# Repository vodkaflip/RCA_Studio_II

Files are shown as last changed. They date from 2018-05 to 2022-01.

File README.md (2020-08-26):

# RCA Studio II

## Multicart Hardware
The cartridge uses a 512k flash chip (SST39SF040) to provide 128 selectable 4k slots to the RCA Studio II Console. The cartridge has a latch circuit for the higher address lines. The original version of the multicart had a dual retriggerable monostable multi-vibrator (courtesy of Ed Keefe) to ‘repair’ the TPA line, which is crippled on most console cartridge ports. A jumper selects whether the cartridge generates this signal (bridge the top two pins of the jumper, default) or whether it uses the one generated by the console (bottom two pins). The latter is needed for some older versions of the Studio II and for the color clones.

The newer version (v5) of the multicart no longer needs the patch circuit: it mixes in the /MRD signal to generate working CE and OE for the EEPROM to work correctly. 

A switch selects whether $000-$3FF is addressable on the cartridge. This will bypass the console's roms/kernels so that Chip-8 games or alternative kernels can be used.

The Multicart PCB has provisions to replace the two hex encoders that select the ROM slot with a microview arduino. In combination with a single rotary dial, a slot can be selected an activated.

## Updating Multicart
If new ROMs become available, the flash memory on the cartridge can be updated to include these. Note that the entire image (512k) will probably need to be rewritten to the chip. This requires a programmer that supports the 39SF040 flash memory chip, which should be most devices. Since the chip is a PLCC32 package, an adapter is probably needed. Check the AtariAge forums for news and help if needed.

### SLOT STRUCTURE (4096 bytes)
```
$xy000-$xy3FF	KERNEL
$xy400-$xy7FF	Low ROM area
$xy800-$xyBFF	[not used by cart - console RAM]
$xyC00-$xyFFF	High ROM area

where	x = high bank select (MSB)
	    y = low bank select (LSB)
```

See the readme in the eeprom directory for more details on how the eeprom image can be 'compiled'.

## Single cart Hardware
This is very similar to the multicart design, apart from the slot selection rotary encoders. And it uses a much smaller eprom: 2716 or 2732 - this needs to be set via a jumper. A switch (or jumper) can determine whether the console uses $000-$3ff from the cartridge or from the console. It allows different kernels to be run from the cart (e.g. Chip-8 games).

## CARTRIDGE SLOT
Since the cartridge slot is unprotected on this 40 year old console, corrosion of the contacts is very likely. This will hamper correct operation of the cartridge and is a likely source of problems/crashes you may experience. If that’s the case, please ensure that the cartridge slot pins on the back row are clean. Use contact cleaner or similar if necessary.

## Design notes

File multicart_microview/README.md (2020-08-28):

# Alternative for Hex Selection

Revisions 4.5 and 5.0 of the RCA Studio II Multicart can accomodate a Sparkfun Microview module with built-in OLED screen for selecting the ROM slots. Selection is done using a single rotary encoder: dial to select a slot and push to activate. The console then needs to be reset to start the game.

## Hardware

The two hex encoders and the resistor network can be removed. The following components need to be added:

* Mechanical Encoder: Bourns PEC12R-4120F-S0012 (https://www.mouser.be/ProductDetail/652-PEC12R-4120F-S12)
* Sparkfun Microview: https://www.mouser.be/Search/Refine?Keyword=microview
* C1-C4: 0.1uF
* optional: a 6-pin header to connect an FTDI interface that allows the Microview module to be reprogrammed (if it is not socketed)

## Software
### Splash Screen

### Main

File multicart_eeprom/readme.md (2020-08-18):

The python 3 script *create_rom.py* compiles an image for the eeprom on the multicart. When using a 512k eeprom like the 39sf040, there’s 8 banks of 16 slots available.

```
Bank0
   ——— 0-game0_1.bin
   ——— 1-game0_2.bin
   ——— …
   ——— e-game0_14.bin
   ——— f-empty.bin
Bank1
   ——— 0-game1_1.bin
   ———…
…
Bank7
   ——— 0-game1_1.bin
   ——— 1-game0_2.bin
   ——— …
   ——— e-game0_14.bin
   ——— f-empty.bin
```

The script will add the appropriate kernel before the game rom. Each 4k slot will have the following structure:
```
$000 - $3ff = kernel
$400 - $7ff = game rom
$800 - $bff = dummy value - this area is not mapped to the cartridge
$c00 - $fff = game rom (only for larger games)
```

The script will decide which kernel to use based on the extension of the game rom:
```
.bin --> standard RCA Studio II kernel
.vic --> Victory/MPA-02/PAL clone kernel
.ch8 --> chip8 kernel by Marcel
```

Note that not all chip8 game will work and even if they do, the keyboard layout may not make much sense.

The script will insert the ROM filename at $a00 - this enables the Emma 02 emulator to display the name of the ROM when using the multicart binary image.

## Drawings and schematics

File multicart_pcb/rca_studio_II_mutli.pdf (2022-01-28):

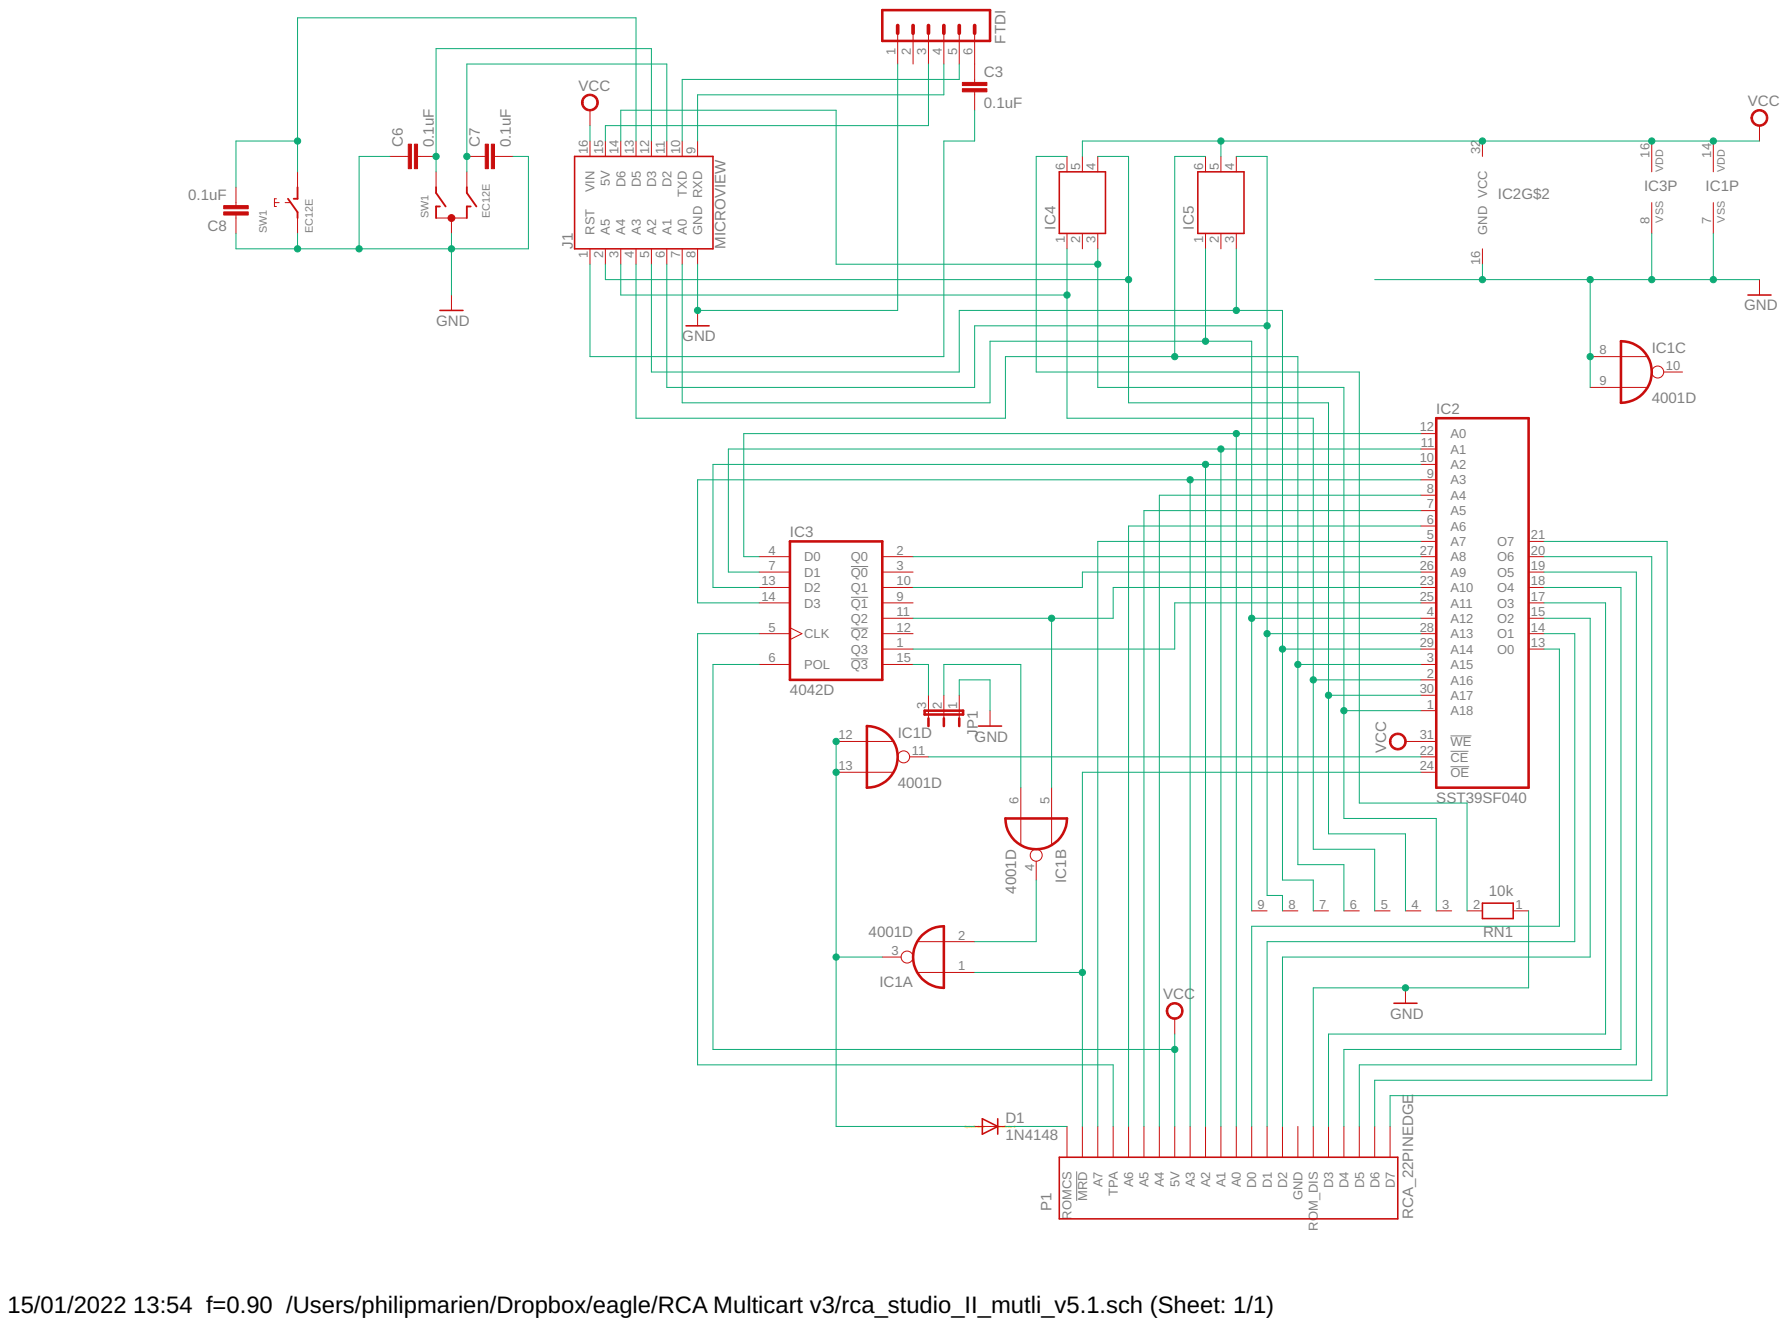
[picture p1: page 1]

VCC

15/01/2022 13:54 f=0.90 /Users/philipmarien/Dropbox/eagle/RCA Multicart v3/rca_studio_II_mutli_v5.1.sch (Sheet: 1/1)

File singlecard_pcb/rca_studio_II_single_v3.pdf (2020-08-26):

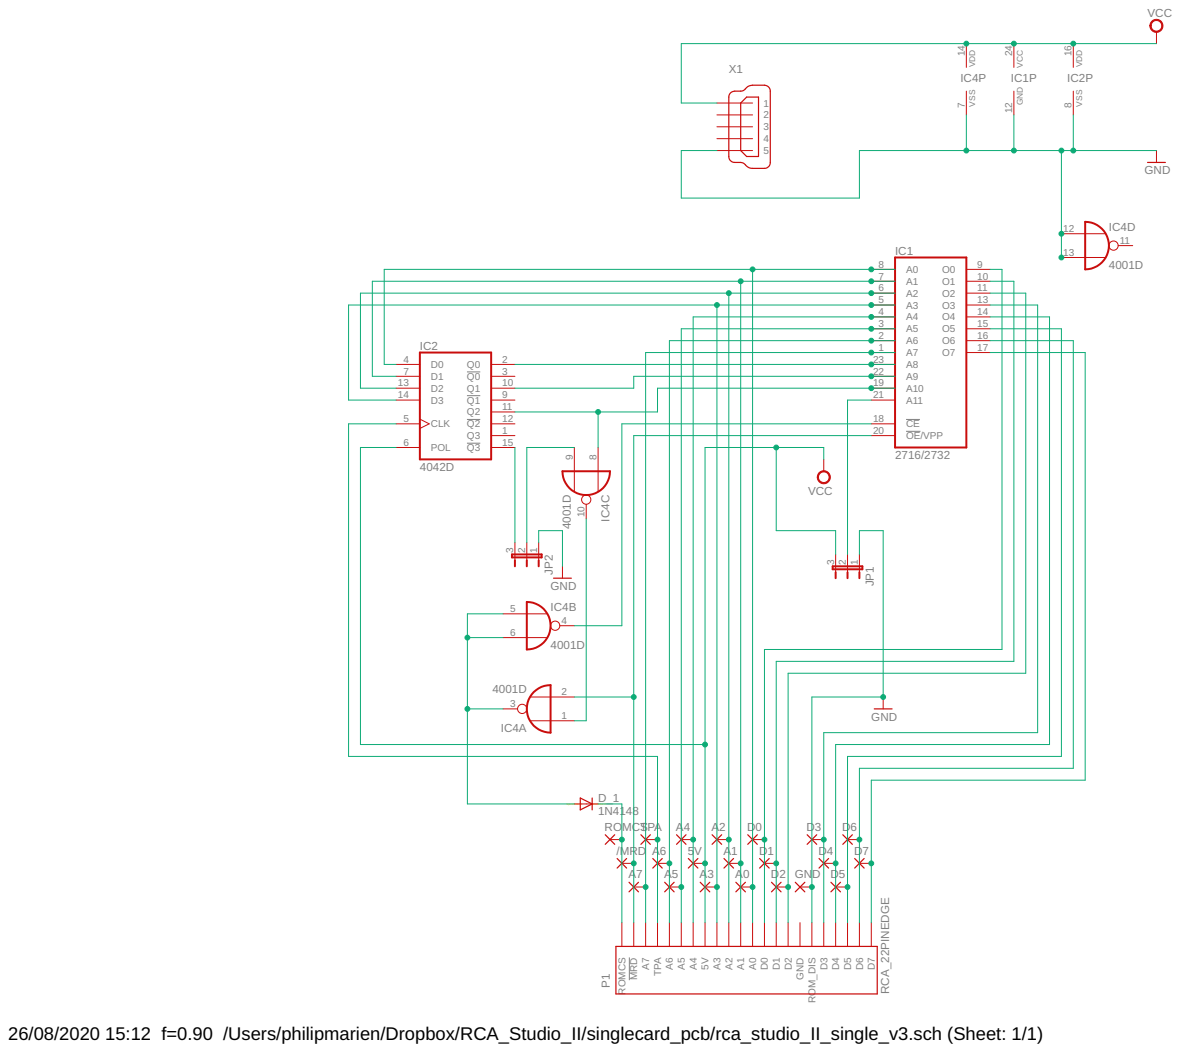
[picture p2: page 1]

26/08/2020 15:12 f=0.90 /Users/philipmarien/Dropbox/RCA_Studio_II/singlecard_pcb/rca_studio_II_single_v3.sch (Sheet: 1/1)

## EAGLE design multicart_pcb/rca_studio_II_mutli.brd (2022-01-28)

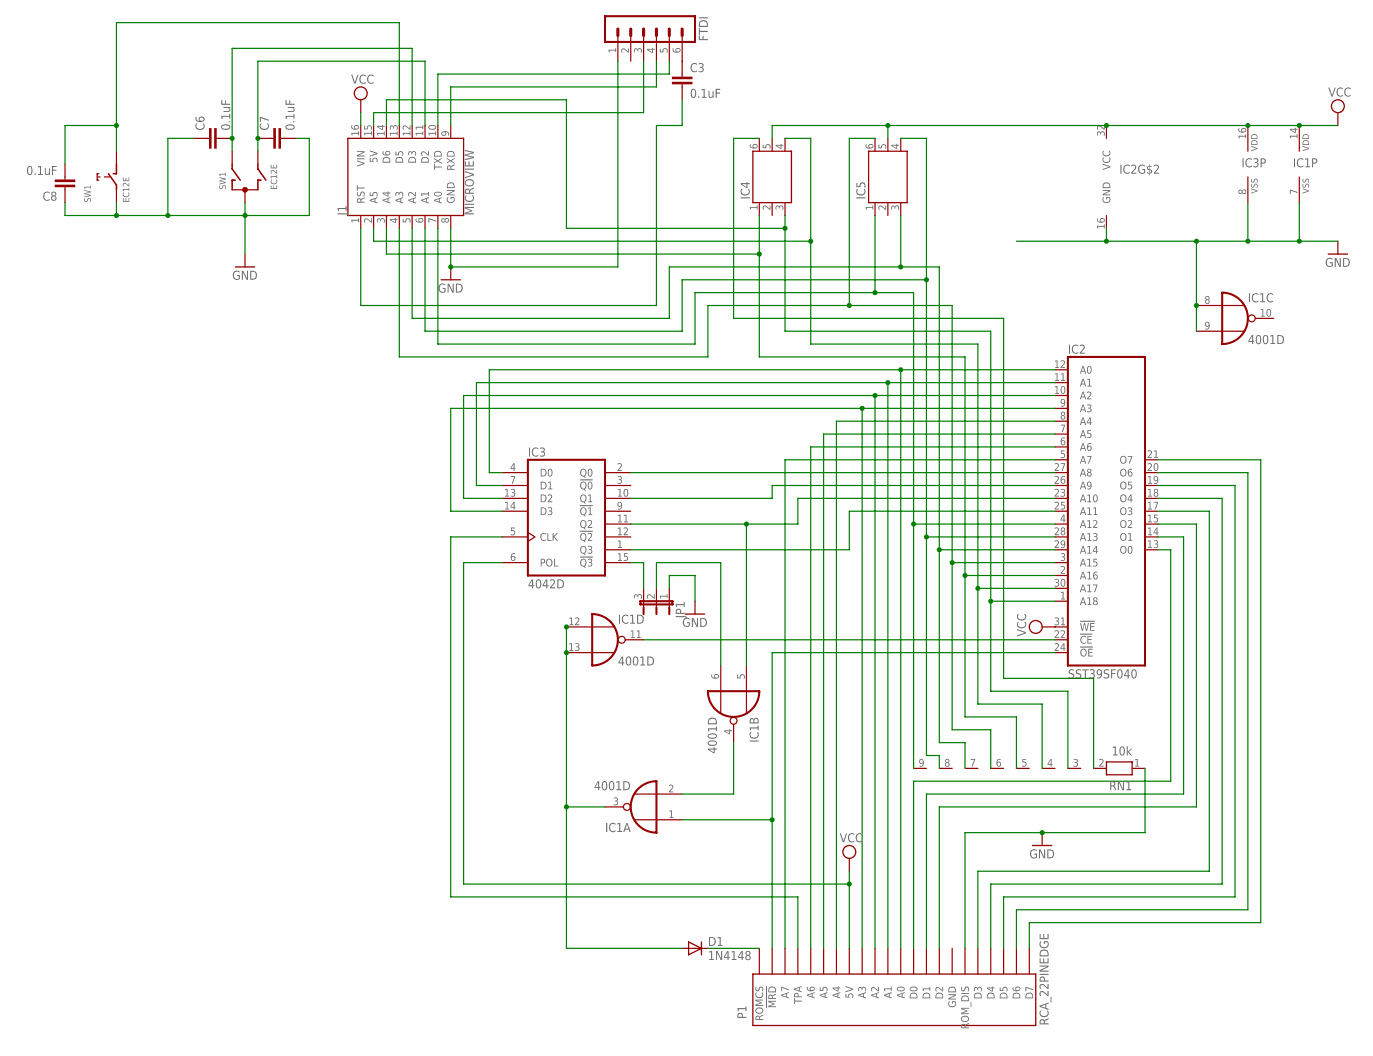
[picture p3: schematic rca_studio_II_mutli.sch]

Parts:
C3, C6, C7, C8: 0.1uF; C0805
D1: 1N4148; DO35-7
FTDI: MA06-1
IC1: 4001D; SO14
IC2: SST39SF040; S32
IC3: 4042D; SO16
IC4, IC5: HEXENCODERHEXENCODER; HEXENCODER
J1: MICROVIEW; MV-DIP16-NODIMENSION
JP1: JP2E; JP2
P1: RCA_22PINEDGE
RN1: 10k; RN-9
SW1: EC12E; ALPS_EC12E_SW

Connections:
A0: IC2.12 (A0), IC3.4 (D0), P1.11 (A0)
A1: IC2.11 (A1), IC3.7 (D1), P1.12 (A1)
A2: IC2.10 (A2), IC3.13 (D2), P1.13 (A2)
A3: IC2.9 (A3), IC3.14 (D3), P1.14 (A3)
A4: IC2.8 (A4), P1.16 (A4)
A5: IC2.7 (A5), P1.17 (A5)
A6: IC2.6 (A6), P1.18 (A6)
A7: IC2.5 (A7), P1.20 (A7)
A8: IC2.27 (A8), IC3.2 (Q0)
A9: IC2.26 (A9), IC3.10 (Q1)
A10: IC1.5 (I0), IC2.23 (A10), IC3.11 (Q2)
A11: IC2.25 (A11), IC3.1 (Q3)
A12: IC2.4 (A12), IC5.1, J1.7 (A0), RN1.9
A13: IC2.28 (A13), IC5.4 (2), J1.6 (A1), RN1.8
A14: IC2.29 (A14), IC5.3 (4), J1.5 (A2), RN1.7
A15: IC2.3 (A15), IC5.6 (8), J1.4 (A3), RN1.6
A16: IC2.2 (A16), IC4.1, J1.3 (A4), RN1.5
A17: IC2.30 (A17), IC4.4 (2), J1.2 (A5), RN1.4
A18: IC2.1 (A18), IC4.3 (4), J1.14 (D6), RN1.3
GND: C6.1, C7.2, C8.1, FTDI.1, IC1.7 (VSS), IC1.8 (I0), IC1.9 (I1), IC2.16 (GND), IC3.8 (VSS), J1.8 (GND), JP1.1, P1.6 (ROM_DIS), RN1.1, SW1.C, SW1.E (2)
unnamed: IC1.11 (O), IC2.22 (!CE)
unnamed: IC2.21 (O7), P1.1 (D7)
unnamed: IC2.20 (O6), P1.2 (D6)
unnamed: IC2.19 (O5), P1.3 (D5)
unnamed: IC2.18 (O4), P1.4 (D4)
unnamed: IC2.17 (O3), P1.5 (D3)
unnamed: IC2.15 (O2), P1.8 (D2)
unnamed: IC2.14 (O1), P1.9 (D1)
unnamed: IC2.13 (O0), P1.10 (D0)
unnamed: C6.2, J1.12 (D3), SW1.A
unnamed: IC1.1 (I0), IC2.24 (!OE), P1.21 (!MRD)
unnamed: C7.1, J1.11 (D2), SW1.B
unnamed: IC1.2 (I1), IC1.4 (O)
unnamed: D1.A, IC1.3 (O), IC1.12 (I0), IC1.13 (I1)
unnamed: C8.2, J1.13 (D5), SW1.D (1)
unnamed: IC3.15 (!Q3), JP1.3
unnamed: FTDI.3, J1.15 (5V)
unnamed: FTDI.4, J1.9 (RXD)
unnamed: FTDI.5, J1.10 (TXD)
unnamed: C3.2, J1.1 (RST)
unnamed: C3.1, FTDI.6
unnamed: IC1.6 (I1), JP1.2
unnamed: D1.C, P1.22 (ROMCS)
unnamed: IC4.6 (8), RN1.2
unnamed: IC3.5 (CLK), P1.19 (TPA)
VCC: IC1.14 (VDD), IC2.31 (!WE), IC2.32 (VCC), IC3.6 (POL), IC3.16 (VDD), IC4.5 (C2), IC5.5 (C2), J1.16 (VIN), P1.15 (5V)

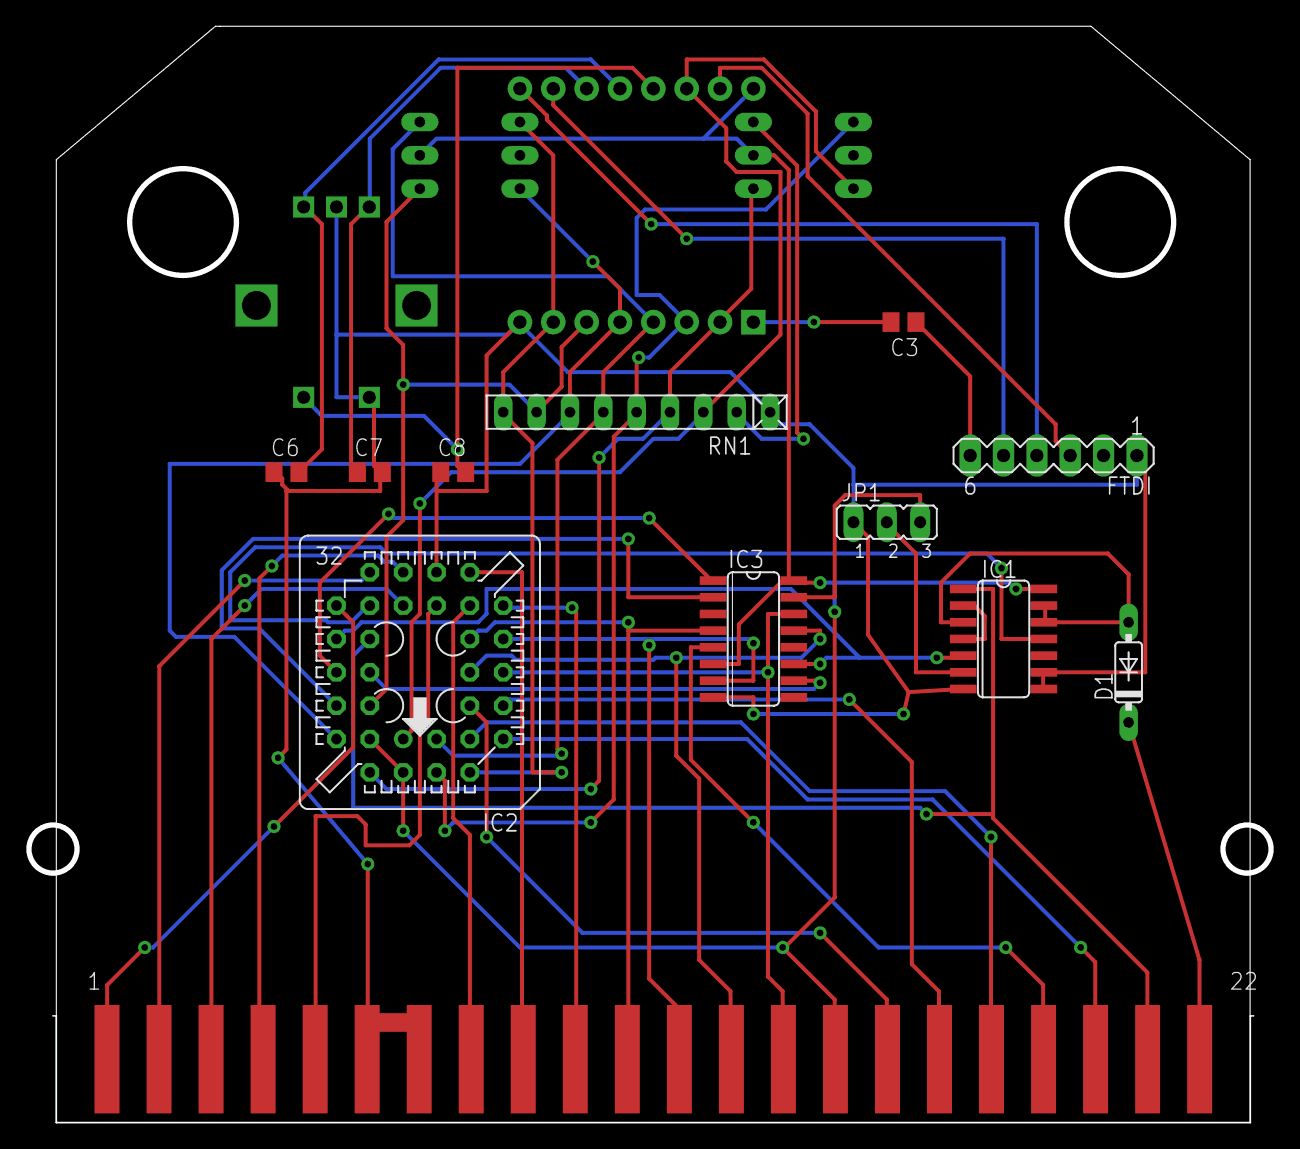
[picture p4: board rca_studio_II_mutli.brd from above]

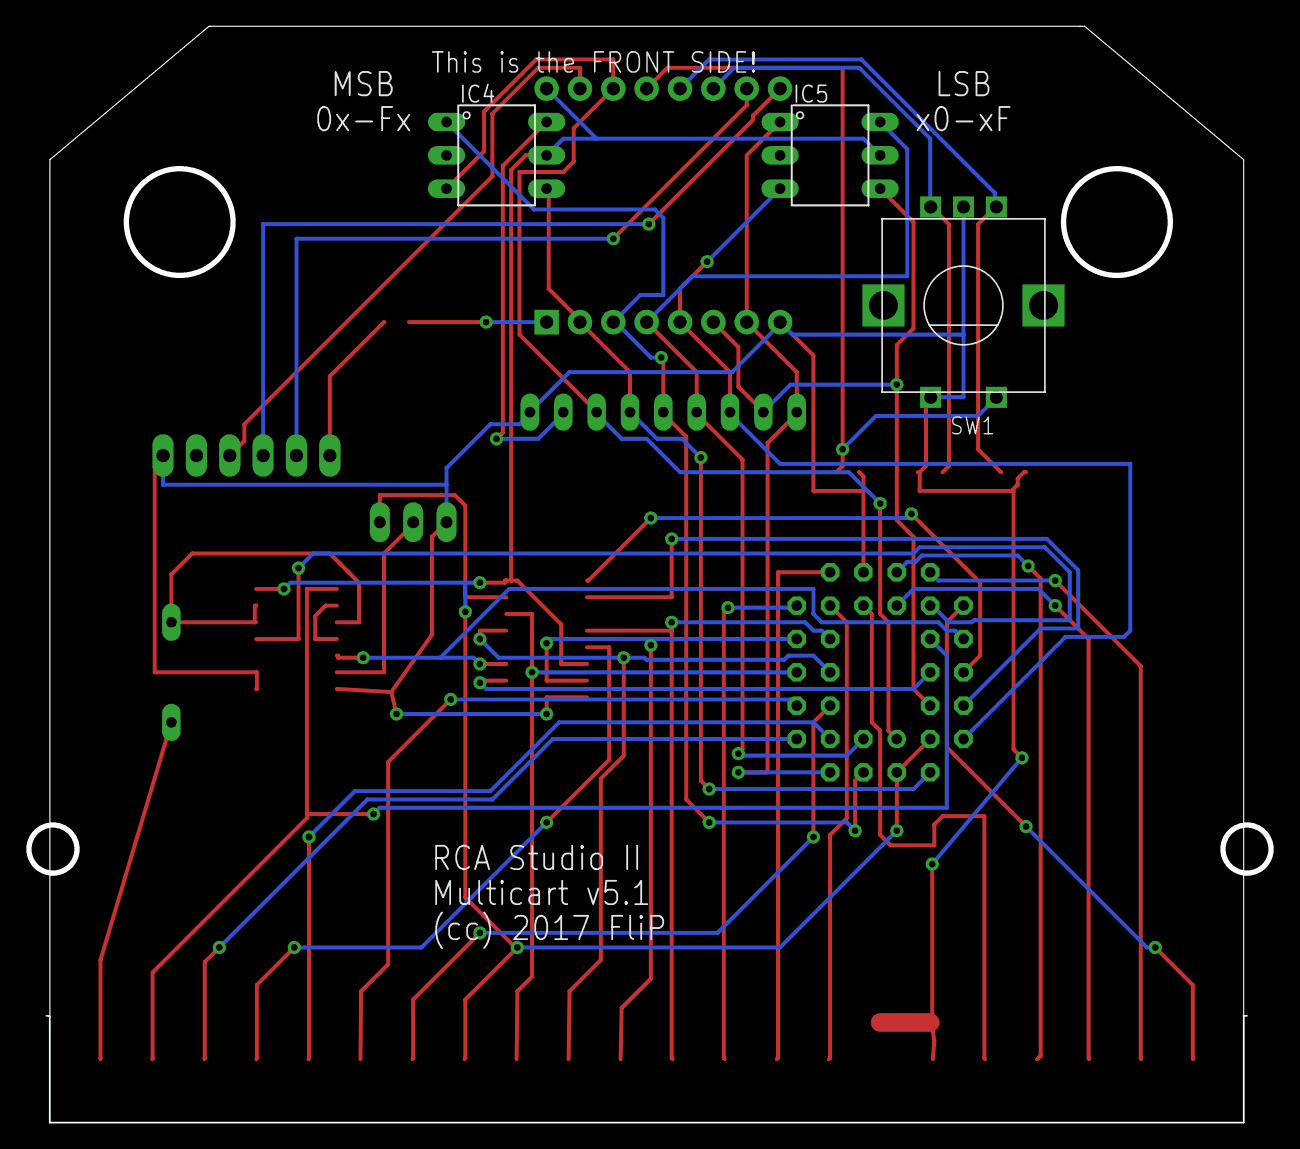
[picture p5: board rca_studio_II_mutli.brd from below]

Board: 2 copper layers, 94.6 x 83.5 mm, 16 parts (4 on the bottom side), 46 nets.

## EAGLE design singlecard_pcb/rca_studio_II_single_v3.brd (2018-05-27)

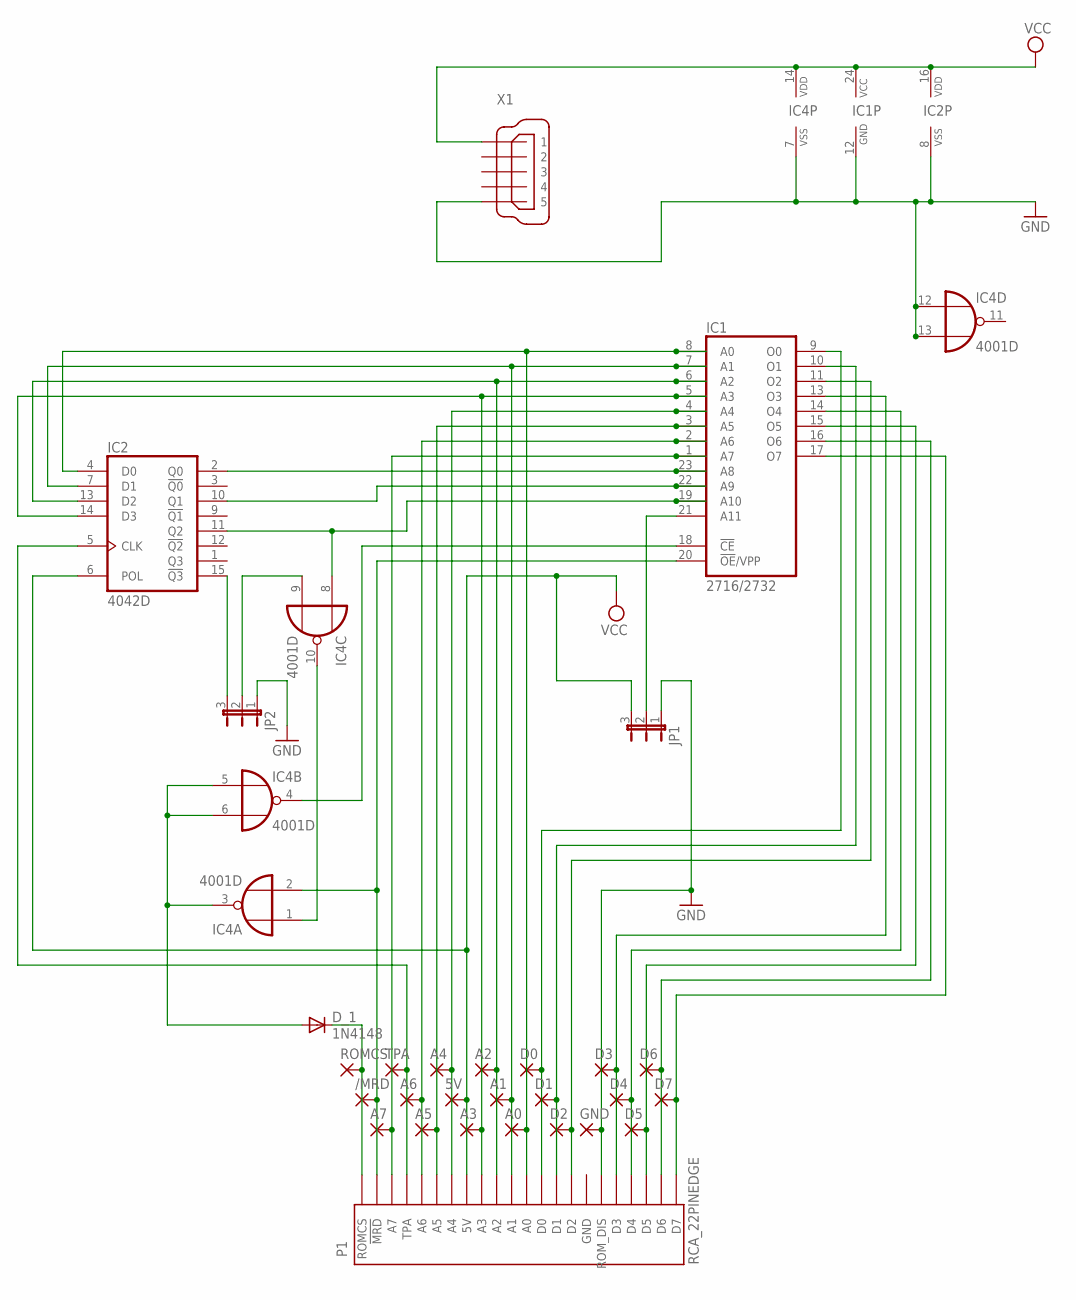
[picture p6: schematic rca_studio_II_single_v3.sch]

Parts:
5V: WIREPAD2,15/1,0; 2,15/1,0
/MRD: WIREPAD2,15/1,0; 2,15/1,0
A0, A1, A2, A3, A4, A5, A6, A7: WIREPAD2,15/1,0; 2,15/1,0
D0, D1, D2, D3, D4, D5, D6, D7: WIREPAD2,15/1,0; 2,15/1,0
D_1: 1N4148; DO35-7
GND: WIREPAD2,15/1,0; 2,15/1,0
IC1: 2716/2732; DIL24
IC2: 4042D; SO16
IC4: 4001D; SO14
JP1, JP2: JP2E; JP2
P1: RCA_22PINEDGE
ROMCS: WIREPAD2,15/1,0; 2,15/1,0
TPA: WIREPAD2,15/1,0; 2,15/1,0
X1: MINI-USB-32005-301; 32005-301

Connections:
01: D1.1, IC1.10 (O1), P1.9 (D1)
/MRD: /MRD.1, IC1.20 (!OE!/VPP), IC4.2 (I1), P1.21 (!MRD)
A0: A0.1, IC1.8 (A0), IC2.4 (D0), P1.11 (A0)
A1: A1.1, IC1.7 (A1), IC2.7 (D1), P1.12 (A1)
A2: A2.1, IC1.6 (A2), IC2.13 (D2), P1.13 (A2)
A3: A3.1, IC1.5 (A3), IC2.14 (D3), P1.14 (A3)
A4: A4.1, IC1.4 (A4), P1.16 (A4)
A5: A5.1, IC1.3 (A5), P1.17 (A5)
A6: A6.1, IC1.2 (A6), P1.18 (A6)
A7: A7.1, IC1.1 (A7), P1.20 (A7)
A8: IC1.23 (A8), IC2.2 (Q0)
A9: IC1.22 (A9), IC2.10 (Q1)
A10: IC1.19 (A10), IC2.11 (Q2), IC4.8 (I0)
A11: IC1.21 (A11), JP1.2
D0: D0.1, IC1.9 (O0), P1.10 (D0)
D2: D2.1, IC1.11 (O2), P1.8 (D2)
D3: D3.1, IC1.13 (O3), P1.5 (D3)
D4: D4.1, IC1.14 (O4), P1.4 (D4)
D5: D5.1, IC1.15 (O5), P1.3 (D5)
D6: D6.1, IC1.16 (O6), P1.2 (D6)
D7: D7.1, IC1.17 (O7), P1.1 (D7)
GND: GND.1, IC1.12 (GND), IC2.8 (VSS), IC4.7 (VSS), IC4.12 (I0), IC4.13 (I1), JP1.1, JP2.1, P1.6 (ROM_DIS), X1.5
unnamed: IC4.1 (I0), IC4.10 (O)
unnamed: IC4.9 (I1), JP2.2
unnamed: IC1.18 (!CE), IC4.4 (O)
unnamed: D_1.A, IC4.3 (O), IC4.5 (I0), IC4.6 (I1)
unnamed: IC2.15 (!Q3), JP2.3
ROMCS: D_1.C, P1.22 (ROMCS), ROMCS.1
TPA: IC2.5 (CLK), P1.19 (TPA), TPA.1
VCC: 5V.1, IC1.24 (VCC), IC2.6 (POL), IC2.16 (VDD), IC4.14 (VDD), JP1.3, P1.15 (5V), X1.1

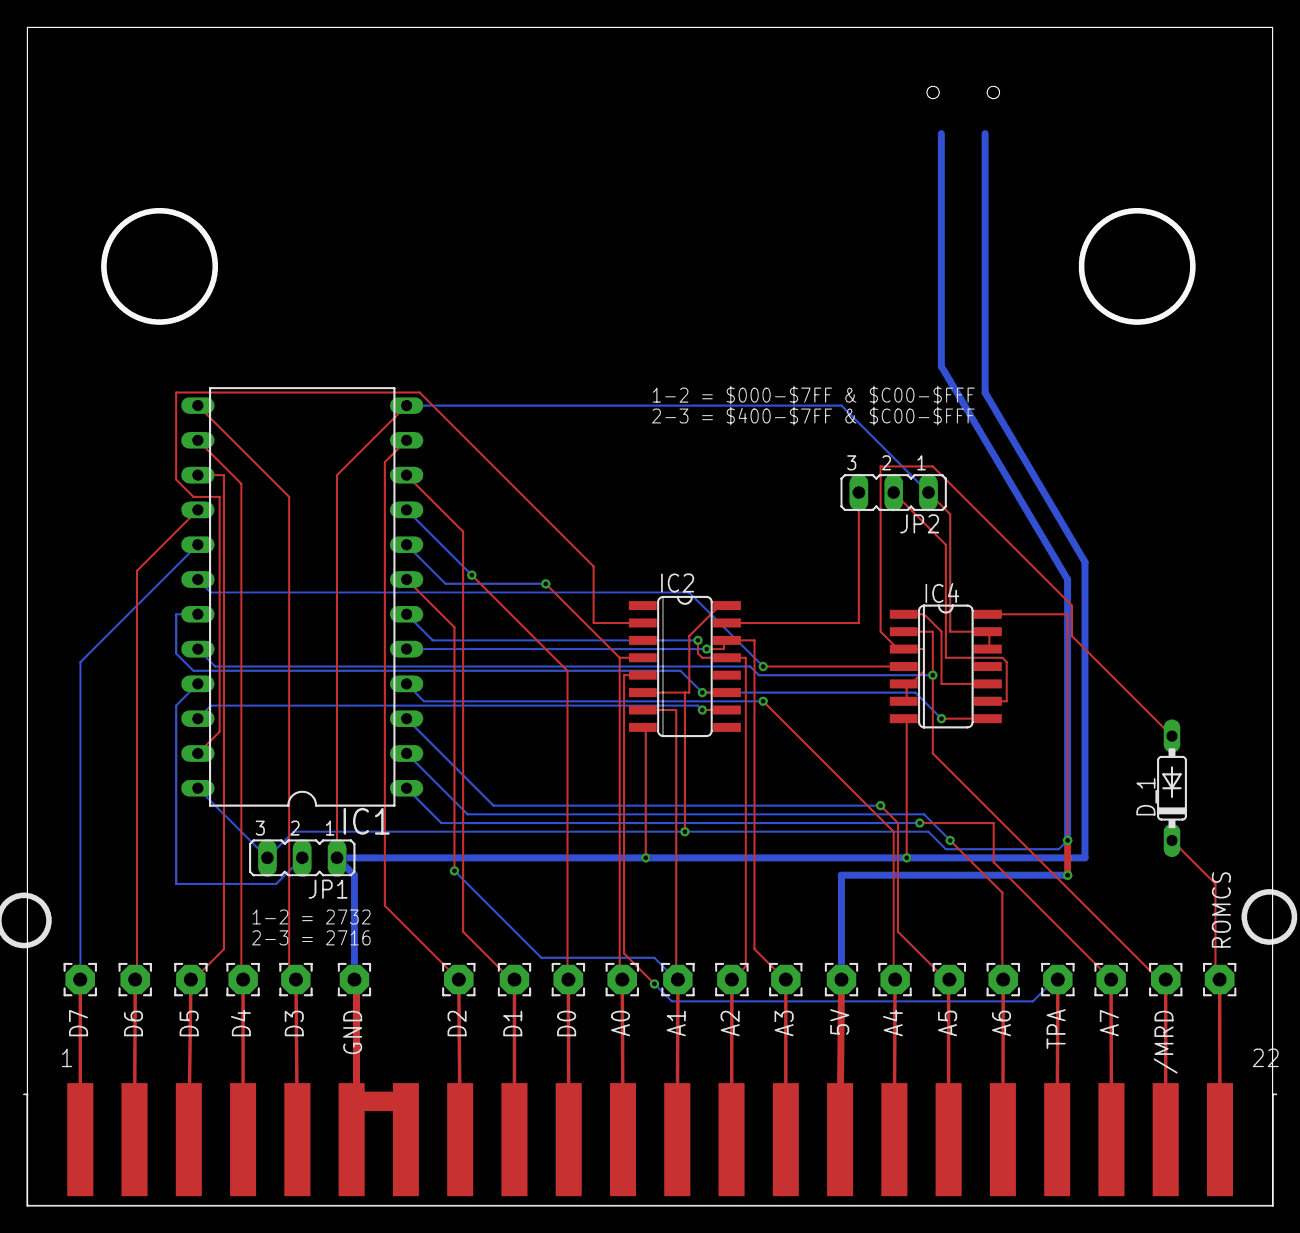
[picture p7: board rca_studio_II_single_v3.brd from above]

Board: 2 copper layers, 90.9 x 86.0 mm, 29 parts (1 on the bottom side), 30 nets.

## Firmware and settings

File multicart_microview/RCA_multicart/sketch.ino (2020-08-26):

// RCA Multicart - Rotary Switch Alternative
// Using a Sparkview Microview and a rotary switch, cartridge slots can be selected
// written by FliP 2018
// 
// v1.0 - initial release
// v1.1 - uses logo stored in EEPROM to reduce variable usage and critical memory usage
//
//####################################################################################

#include <MicroView.h>
#include <Bounce2.h>
#include <EEPROM.h>

static const int kPin_A12  = A0; // Microview pin 7 / A0
static const int kPin_A13  = A1; // Microview pin 6 / A1
static const int kPin_A14  = A2; // Microview pin 5 / A2
static const int kPin_A15  = A3; // Microview pin 4 / A3

static const int kPin_A16  = A4; // Microview pin 3 / A4
static const int kPin_A17  = A5; // Microview pin 2 / A5
static const int kPin_A18  = 6; // Microview pin 14 / D6

static const int kPin_push = 5; // Microview 13 / D5
const unsigned int usedSlots[] = {0,1,2,3,4,5,6,7,8,9,10,11,
                                  16,17,18,19,20,21,22,23,24,25,26,27,28,29,30,
                                  32,33,34,35,36,37,38,39,
                                  48,49,50,51,52,
                                  64,65,66,67,68,69,70,
                                  80,81,82};
const char *banks[] = {"RCA Orig.","PAL Clones","P.Robson","L.Romanow","Other","CHIP-8"};
const char *slots[] = {"Studio II ROM","Space War","Fun with  Numbers","Tennis/   Squash","Baseball","Speedway/ Tag","GunfighterMoonship  Battle","School    House I","School    House II","Blackjack","Bingo","Biorytm",
                       "Grand Pack","Space War","Fun with  Numbers","Tennis/   Squash","Baseball","Speedway/ Tag","GunfighterMoonship  Battle","School    House I","School    House II","Blackjack","Bingo","Biorytm","Concentr. Match","Star Wars","Pinball",
                       "Asteroids","Berzerk","Combat","Hockey/   Pong","Invaders","Kaboom","Pacman","Scramble",
                       "Climber","Outbreak","Rocket","TVA2012","Fifteen",
                       "Prog Cart","H/W Test","ROM       Checksum","Mem Test","Keypad    Test","RCA Test","RCA Demo",
                       "Addition","Tetris","Airplane"
                      };

int slotCount = 50;

static int pinA = 2; // Our first hardware interrupt pin is digital pin 2
static int pinB = 3; // Our second hardware interrupt pin is digital pin 3
volatile byte aFlag = 0; // let's us know when we're expecting a rising edge on pinA to signal that the encoder has arrived at a detent
volatile byte bFlag = 0; // let's us know when we're expecting a rising edge on pinB to signal that the encoder has arrived at a detent (opposite direction to when aFlag is set)
volatile byte encoderPos = 128; //this variable stores our current value of encoder position. Change to int or uin16_t instead of byte if you want to record a larger range than 0-255
volatile byte oldEncPos = 128; //stores the last encoder position value so we can compare to the current reading and see if it has changed (so we know when to print to the serial monitor)
volatile byte reading = 0; //somewhere to store the direct values we read from our interrupt pins before checking to see if we have moved a whole detent

Bounce debounce_push = Bounce();
long position = 0;
unsigned int selectedSlot = EEPROM.read(0);

void setup() {
  Serial.begin(9600);
  uView.begin();
  uView.clear(PAGE);
  pinMode(kPin_A12, OUTPUT);
  digitalWrite(kPin_A12,LOW);
  pinMode(kPin_A13, OUTPUT);
  digitalWrite(kPin_A13,LOW);
  pinMode(kPin_A14, OUTPUT);
  digitalWrite(kPin_A14,LOW);
  pinMode(kPin_A15, OUTPUT);
  digitalWrite(kPin_A15,LOW);
  pinMode(kPin_A16, OUTPUT);
  digitalWrite(kPin_A16,LOW);
  pinMode(kPin_A17, OUTPUT);
  digitalWrite(kPin_A17,LOW);
  pinMode(kPin_A18, OUTPUT);
  digitalWrite(kPin_A18,LOW);
  SetSlot(usedSlots[selectedSlot]);

  
  pinMode(kPin_push, INPUT_PULLUP);
  debounce_push.attach(kPin_push);
  debounce_push.interval(100);
  pinMode(pinA, INPUT_PULLUP); // set pinA as an input, pulled HIGH to the logic voltage (5V or 3.3V for most cases)
  pinMode(pinB, INPUT_PULLUP); // set pinB as an input, pulled HIGH to the logic voltage (5V or 3.3V for most cases)
  attachInterrupt(0,PinA,RISING); // set an interrupt on PinA, looking for a rising edge signal and executing the "PinA" Interrupt Service Routine (below)
  attachInterrupt(1,PinB,RISING); // set an interrupt on PinB, looking for a rising edge signal and executing the "PinB" Interrupt Service Routine (below)

  //splash
  // width: 64 height: 48 = 384 bytes
  // stored in EEPROM from position 16 to 400

unsigned int i,j;
for (i=0; i<6; i++) {
    uView.setPageAddress(i);
    uView.setColumnAddress(0);
    for (j=0;j<0x40;j++) {
      uView.data(EEPROM.read(i*0x40+j+16));
    }
}
delay(4000);
oldEncPos = encoderPos;
}

void PinA(){
  cli(); //stop interrupts happening before we read pin values
  reading = PIND & 0xC; // read all eight pin values then strip away all but pinA and pinB's values
  if(reading == B00001100 && aFlag) { //check that we have both pins at detent (HIGH) and that we are expecting detent on this pin's rising edge
    encoderPos --; //decrement the encoder's position count
    bFlag = 0; //reset flags for the next turn
    aFlag = 0; //reset flags for the next turn
  }
  else if (reading == B00000100) bFlag = 1; //signal that we're expecting pinB to signal the transition to detent from free rotation
  sei(); //restart interrupts
}

void PinB(){
  cli(); //stop interrupts happening before we read pin values
  reading = PIND & 0xC; //read all eight pin values then strip away all but pinA and pinB's values
  if (reading == B00001100 && bFlag) { //check that we have both pins at detent (HIGH) and that we are expecting detent on this pin's rising edge
    encoderPos ++; //increment the encoder's position count
    bFlag = 0; //reset flags for the next turn
    aFlag = 0; //reset flags for the next turn
  }
  else if (reading == B00001000) aFlag = 1; //signal that we're expecting pinA to signal the transition to detent from free rotation
  sei(); //restart interrupts
}

// set IO pins on microView to selected address/slot
void SetSlot(int slot) {  
  digitalWrite(kPin_A12, (slot & 1)?HIGH:LOW);
  digitalWrite(kPin_A13, (slot & 2)?HIGH:LOW);
  digitalWrite(kPin_A14, (slot & 4)?HIGH:LOW);
  digitalWrite(kPin_A15, (slot & 8)?HIGH:LOW);
  digitalWrite(kPin_A16, (slot & 16)?HIGH:LOW);
  digitalWrite(kPin_A17, (slot & 32)?HIGH:LOW);
  digitalWrite(kPin_A18, (slot & 64)?HIGH:LOW);
}

void loop() {
    if(oldEncPos != encoderPos) {
        if (oldEncPos < encoderPos) { // CCW
          if (selectedSlot > 0) {selectedSlot--;} else {selectedSlot = slotCount - 1;}
          } else { //CW
          if (selectedSlot < (slotCount-1)) {selectedSlot++;} else {selectedSlot = 0;}
        }
      oldEncPos = encoderPos;
    }    

      // write the title to the screen
      uView.clear(PAGE);
      uView.setFontType(0);
      uView.setCursor(0,0);
      uView.print(banks[usedSlots[selectedSlot] >> 4]);
      uView.line(0,8,63,8);
      uView.setCursor(0,12);
      uView.print(slots[selectedSlot]);
      uView.display();

      // check for button press
      debounce_push.update();
      int btnPushed = debounce_push.fell();
      // if button was pressed, flash screen, set the new selected slot and store selected slot in EEPROM (retrieve after power down)
      if (btnPushed) {
        SetSlot(usedSlots[selectedSlot]);
        uView.invert(1);
        delay(250);
        uView.invert(0);
        EEPROM.write(0,selectedSlot);
      }
}

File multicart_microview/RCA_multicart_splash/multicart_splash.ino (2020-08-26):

// RCA Multicart - Rotary Switch Alternative
// Writes Multicart logo splash to EEPROM 
// written by FliP 2018
// 
// v1.0 - initial release
//
//////////////////////////////////////////////////////
#include <EEPROM.h>
#include <MicroView.h>

int addr =0;
const unsigned char splash[] = {
0x00, 0x00, 0x00, 0xFE, 0xFE, 0xFE, 0xFE, 0xFE, 0xFE, 0xFE, 0x06, 0x06, 0xFE, 0xFE, 0xFE, 0xFE,
0xFE, 0xFE, 0xFC, 0x00, 0x00, 0x00, 0x00, 0x00, 0xF8, 0xFC, 0xFE, 0xFE, 0xFE, 0xFE, 0xFE, 0x06,
0x06, 0xFE, 0xFE, 0xFE, 0xFE, 0xFE, 0xFE, 0xFC, 0xF0, 0x00, 0x00, 0x00, 0x00, 0x00, 0xC0, 0xF8,
0xFE, 0xFE, 0xFE, 0xFE, 0x06, 0x06, 0xFE, 0xFE, 0xFE, 0xFE, 0xFE, 0xFE, 0xFE, 0x00, 0x00, 0x00,
0x00, 0x00, 0x00, 0xFF, 0xFF, 0xFF, 0xFF, 0xFF, 0xFF, 0xFF, 0x00, 0x00, 0x07, 0x1F, 0xFF, 0xFF,
0xFF, 0xFF, 0xFD, 0xF0, 0xC0, 0x00, 0x00, 0x00, 0x3F, 0x7F, 0xFF, 0xFF, 0xFF, 0xFF, 0xFF, 0xC0,
0xC0, 0xFE, 0xFE, 0xFE, 0xFE, 0xFE, 0xFE, 0x7E, 0x1E, 0x00, 0x80, 0xE0, 0xFC, 0xFF, 0xFF, 0xFF,
0xFF, 0xFF, 0x1F, 0x07, 0x00, 0x00, 0xFF, 0xFF, 0xFF, 0xFF, 0xFF, 0xFF, 0xFF, 0x00, 0x00, 0x00,
0x00, 0xE0, 0xF0, 0x18, 0x08, 0x78, 0x18, 0x00, 0x80, 0x80, 0xE0, 0xF0, 0x88, 0x00, 0x00, 0x80,
0x80, 0x80, 0x00, 0x00, 0x80, 0x80, 0x00, 0x00, 0x00, 0x00, 0x00, 0x80, 0x80, 0xC0, 0xF8, 0x3C,
0x06, 0x06, 0x86, 0x98, 0x18, 0x00, 0x00, 0x00, 0x80, 0x80, 0x80, 0x00, 0x00, 0x00, 0x00, 0x00,
0x00, 0x00, 0x00, 0x08, 0xF8, 0xF8, 0x08, 0x08, 0x00, 0x00, 0x00, 0x08, 0xF8, 0xF8, 0x08, 0x08,
0x80, 0x81, 0x43, 0x7F, 0x3C, 0x00, 0x00, 0x00, 0x78, 0x7F, 0x67, 0x20, 0x30, 0x00, 0x71, 0x7C,
0x27, 0x21, 0x70, 0x7E, 0x2F, 0x21, 0x00, 0x78, 0x7C, 0x63, 0x21, 0x30, 0x7C, 0x3F, 0x33, 0x18,
0x72, 0x7D, 0x3F, 0x13, 0x00, 0x3C, 0x7E, 0x41, 0x40, 0x20, 0x1F, 0x0F, 0x00, 0x00, 0x00, 0x00,
0x40, 0x40, 0x70, 0x7F, 0x4F, 0x00, 0x00, 0x00, 0x40, 0x40, 0x70, 0x7F, 0x4F, 0x00, 0x00, 0x00,
0x00, 0x00, 0x00, 0x00, 0x00, 0x00, 0x00, 0x00, 0x00, 0x00, 0x00, 0x00, 0xFE, 0x06, 0x38, 0xC0,
0x00, 0xC0, 0x38, 0x06, 0xFE, 0x00, 0xF0, 0x00, 0x00, 0x00, 0xF0, 0x00, 0xFE, 0x10, 0xFE, 0x10,
0xF2, 0x00, 0xE0, 0x10, 0x10, 0x10, 0x20, 0x00, 0x20, 0x90, 0x90, 0x90, 0xE0, 0x00, 0xF0, 0x20,
0x10, 0x10, 0xFE, 0x10, 0x00, 0x00, 0x00, 0x00, 0x00, 0x00, 0x00, 0x00, 0x00, 0x00, 0x00, 0x00,
0x00, 0x00, 0x00, 0x00, 0x00, 0x00, 0x00, 0x00, 0x00, 0x00, 0x00, 0x00, 0x07, 0x00, 0x00, 0x03,
0x04, 0x03, 0x00, 0x00, 0x07, 0x00, 0x03, 0x04, 0x04, 0x02, 0x07, 0x00, 0x07, 0x00, 0x07, 0x04,
0x07, 0x00, 0x03, 0x04, 0x04, 0x04, 0x03, 0x00, 0x03, 0x04, 0x04, 0x04, 0x07, 0x00, 0x07, 0x00,
0x00, 0x00, 0x07, 0x04, 0x00, 0x00, 0x00, 0x00, 0x00, 0x00, 0x00, 0x00, 0x00, 0x00, 0x00, 0x00
};

void setup() {
  Serial.begin(9600);
  EEPROM.write(0,0); //start slot
}

void loop() {
// put the splash screen in EEPROM from 0x0010 onwards to save on RAM
  unsigned int i,j;
    for (i=0; i<384; i++) {
    EEPROM.write(i+16,splash[i]);
    Serial.println(i);
    }
while(1) {}
}

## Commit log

2018-05-27 Initial upload
    [rca_studio_II_mutli_v5.brd, rca_studio_II_mutli_v5.sch, rca_studio_II_single_v3.brd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]
2022-01-28 multicart v5.1
    [rca_studio_II_mutli.brd, rca_studio_II_mutli.sch]
